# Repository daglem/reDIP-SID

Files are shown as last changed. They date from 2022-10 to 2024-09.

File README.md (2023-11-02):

# reDIP SID

## MOS 6581/8580 SID FPGA emulation platform
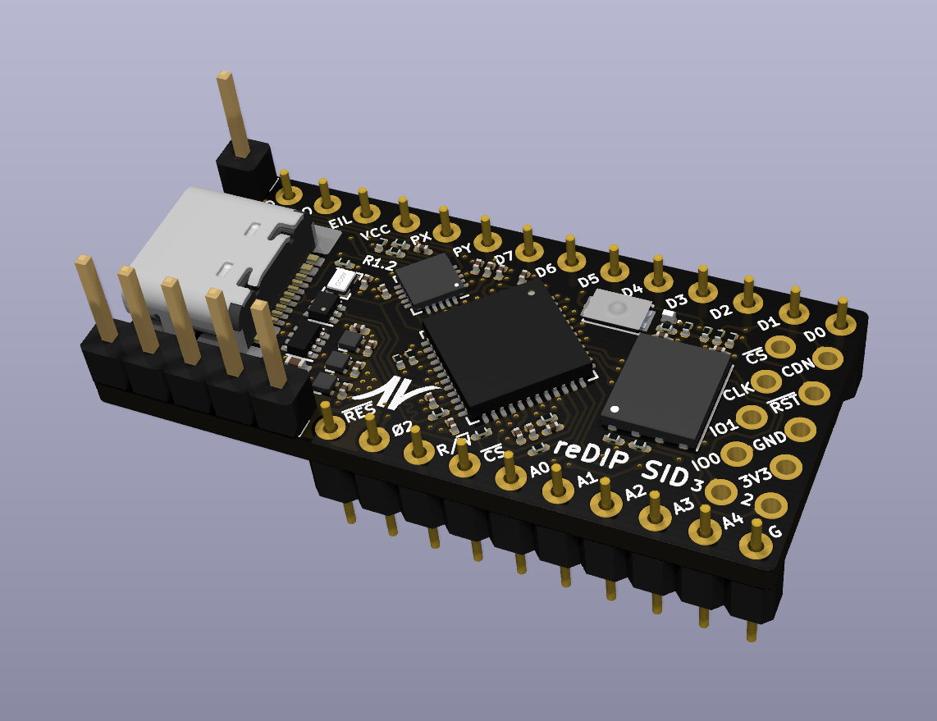
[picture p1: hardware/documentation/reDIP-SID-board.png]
Board


## Overview
The reDIP SID is an open source hardware development board which combines the following in a DIP-28 size package:

* Lattice iCE40UP5K FPGA
* NXP SGTL5000 Audio Codec
* 128Mbit FLASH
* 64Mbit PSRAM
* User LED
* Push button
* USB-C receptacle for power and FPGA Full Speed USB
* 5V tolerant I/O

The reDIP SID provides a fully functional open source hardware platform for MOS 6581/8580 SID emulation.

The reDIP SID also aims to be a good no-frills generic choice for FPGA projects which may find use for audio and/or 5V tolerant I/O -
it should be ideal for for e.g. retro computer and synthesizer projects.

Designs for the iCE40UP5K FPGA can be processed by [yosys](https://github.com/YosysHQ/yosys/) and [nextpnr](https://github.com/YosysHQ/nextpnr/).

The board is supported by the DFU [Nitro Bootloader](https://github.com/no2fpga/no2bootloader/), facilitating simple updates over USB using e.g. [dfu-util](http://dfu-util.sourceforge.net/).

## General use

### I/O interfaces

#### Header pins:

* 12V / 9V input (for SID audio output DC bias / C64 model detection)
* 5V input
* 19 FPGA GPIO
* 3 FPGA current drive / open-drain I/O
* 5 audio pins (stereo line input, stereo line output, SID audio output)
* GND

All FPGA header I/O is 5V tolerant, and can drive 5V TTL. JP1 can be shorted to make the 5V input pin bidirectional, e.g. to power 5V TTL devices from USB VBUS.

Note that the line inputs are not AC coupled - AC coupling must be externally added for audio applications.
Without external AC coupling, the line inputs can conceivably be used as generic ADCs.

The 12V / 9V input is connected to the SGTL5000 mic input via a 1/6 ratio voltage divider.

#### SPI / programming header:

A separate header footprint is provided for (Q)SPI peripherals / flash programming, with pinout borrowed from the [iCEBreaker Bitsy](https://github.com/icebreaker-fpga/icebreaker).

The header provides a 3.3V output, which may be used to power external devices. The 3.3V rail is supplied by a 700mA LDO.

#### USB-C functions:

* 5V power
* FPGA Full Speed USB

## MOS 6581/8580 SID compatibility

The board is fully pin compatible with the venerable MOS 6581/8580 SID sound chip.

The board features three additional address pins which may be connected to the Commodore 64, in order to make a second SID chip appear e.g. at address D420, D500, or DE00.

There is also an additional EXT IN audio input pin for a second SID chip, and separate stereo line output pins which may be connected directly to audio equipment.
Either the SID GND pin or GND on the programming header may be used as audio ground.

Cycle accurate emulation of the SID chip has been implemented in [gateware](gateware/).

## Thanks

Big thanks go to [Sylvain "tnt" Munaut](https://github.com/smunaut/), who has not only implemented support for the reDIP SID in his [Nitro Bootloader](https://github.com/no2fpga/no2bootloader/),
but has also identified shortcomings, suggested feature improvements, and provided invaluable help to ensure that the board actually works.

Thanks must also go to [Aidan Dodds](https://github.com/bit-hack) and [Paul Sajna](https://github.com/sajattack)
for putting the first prototype through its paces working on Dodds' [icesid](https://github.com/bit-hack/icesid), with guidance from Munaut.

## Board Front
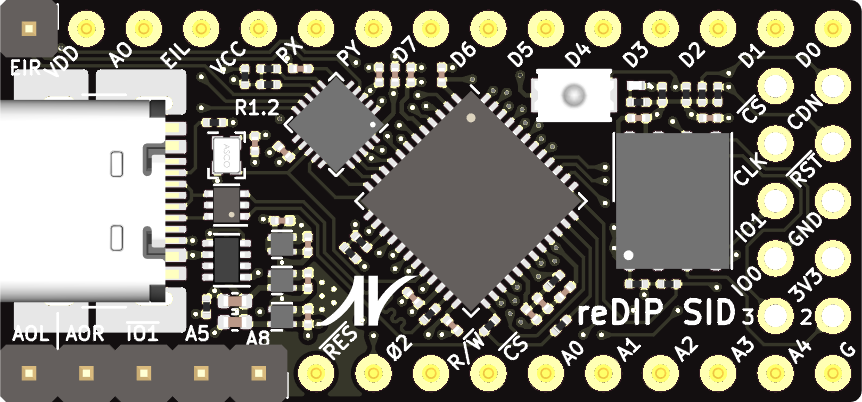
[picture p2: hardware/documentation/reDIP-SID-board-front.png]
Board Front


## Board Back
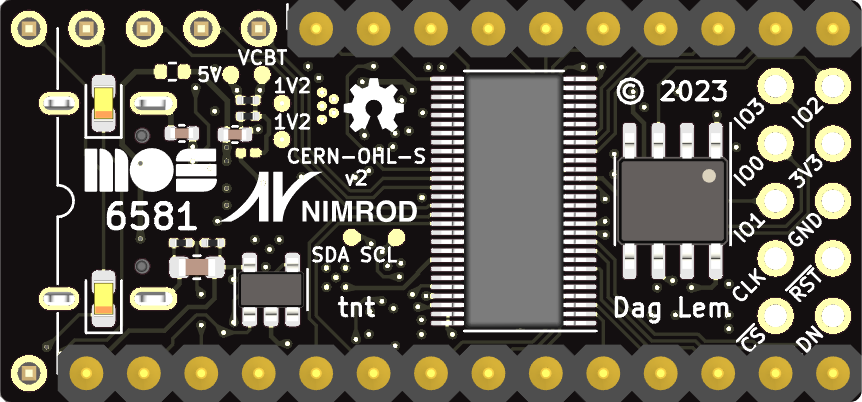
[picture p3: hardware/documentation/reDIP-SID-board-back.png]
Board Back


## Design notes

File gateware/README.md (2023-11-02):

# reDIP SID Gateware

## Description

The reDIP SID FPGA gateware provides high quality SID emulation for the
[reDIP SID](https://github.com/daglem/reDIP-SID) hardware.

The gateware owes its existence to [reSID](https://github.com/daglem/reSID),
the [SID internals documentation](https://github.com/libsidplayfp/SID_schematics/wiki)
by Leandro "drfiemost" Nini and Dieter "ttlworks" Mueller, auxiliary code and
guidance from Sylvain "tnt" Munaut, and a lot of work :-)

The gateware implements cycle accurate emulation of the SID digital logic, and
quite a few SID analog peculiarities. In order to make reasonably accurate
emulation of some of these fit in the iCE40UP5K FPGA, a few novelties have been
invented:

* Combined sawtooth/triangle and pulse/sawtooth/triangle waveforms without lookup tables.
* MOS6581 waveform, envelope, and filter cutoff DAC emulation without lookup tables.
* Parameterizable filter cutoff curves requiring only a single 16kbit lookup table.

Furthermore, FPGA resources are shared by [pipelining](Pipelining.md) and
time-division multiplexing. This is in contrast to the real SID chip, where
there was sufficient die area to simply repeat functional modules for each
voice.

By default, a single MOS6581 chip is emulated. The gateware also implements
MOS8580 emulation and simultaneous emulation of two chips, however runtime
configuration of these features are not yet implemented.

## Installation

The gateware may be installed on the reDIP SID hardware via USB using
[dfu-util](https://dfu-util.sourceforge.net/):

* Connect a USB cable to enter the bootloader. The green LED should start blinking.
* Install the gateware with `./flash.sh` (Linux / Mac OS) or `flash.bat` (Windows).
* Disconnect USB. If the board is still powered, then press the user button to boot.

Depending on the previously installed gateware, in order to enter the
bootloader it may be required to keep the user button pressed while powering up
the board.

## License

This gateware is part of reDIP SID, a MOS 6581/8580 SID FPGA emulation platform.
Copyright (C) 2022 - 2023  Dag Lem \<resid@nimrod.no\>

The source describes Open Hardware and is licensed under the CERN-OHL-S v2.

You may redistribute and modify the source and make products using it under
the terms of the [CERN-OHL-S v2](https://ohwr.org/cern_ohl_s_v2.txt).

This source is distributed WITHOUT ANY EXPRESS OR IMPLIED WARRANTY,
INCLUDING OF MERCHANTABILITY, SATISFACTORY QUALITY AND FITNESS FOR A
PARTICULAR PURPOSE. Please see the CERN-OHL-S v2 for applicable conditions.

Source location: [https://github.com/daglem/reDIP-SID](https://github.com/daglem/reDIP-SID)

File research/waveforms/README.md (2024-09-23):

# OSC3 samples of combined waveforms

MOS6581 waveform samples are supplied by Tuomas "Trurl" Rantala,
generated by combsample.prg for a chip marked 6581R4AR 3488.

MOS8580 waveforms samples are taken from reSID.

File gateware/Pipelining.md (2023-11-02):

# Pipelining

In order to make accurate SID emulation fit on a Lattice iCE40UP5K FPGA, it is
necessary to use pipelining and time-division multiplexing of resources.

Two synchronized pipelines are implemented; the voice pipeline and the filter
pipeline. The combined pipelines have a total of 14 pipeline stages. Two SID
chips are emulated, with audio outputs ready at cycle 15 and 20, respectively.

## Voice pipeline

The voice pipeline combines several SID modules, and produces one voice output
per cycle for two SID chips. The table below depicts the data path for SID 1,
voice 1.

| Stages | Module | Cycle 1 | Cycle 2 | Cycle 3 | Cycle 4 | Cycle 5 | Cycle 6 | Cycle 7 | Cycle 8 |
|  ----: | ---| --- |--- | --- | --- | --- | --- | --- | --- |
|  1 - 3 | Control registers  | Write voice 1  | Write voice 2  | Write voice 3  | | | | | |
|  2 - 4 | Oscillator | | Update osc. 1  | Update osc. 2  | Sync osc. 1-3  | | | | |
|  2 - 6 | Waveform generator | | Buffer pulse 1 | Buffer pulse 2 | Buffer pulse 3 | Waveform select / update | Waveform writeback | | |
|  6 | Envelope generator | | | | | | Update counters | | |
|  6 - 7 | Voice DCA | | | | | | Buffer wav/env | DCA = wav*env | |
| | | | | | | | | | Voice 1 out |

The voice pipeline starts on the falling edge of the ϕ₂ clock, brought into the
FPGA clock domain by a two-stage synchronizer.

As can be seen from the table above, output for voice 1 is ready on cycle
8. Outputs from the waveform and envelope generators are ready on cycle 6, so
data for the read-only registers OSC3 and ENV3 are also ready on cycle 8 (6 +
2).

The oscillator module adds a latency of two cycles; this is required for
synchronization of oscillators.

In order to meet MOS6510 bus timing, writes to the filter control registers for
SID 1 and 2 are included in the voice pipeline at cycle 1 and 4, respectively.
This is not shown in the table above.

## Filter pipeline

A separate pipeline is used to update filter state variables and produce audio
outputs for the two SID chips. The table below depicts the data path for the
audio output of SID 1.

| Stages | Description | Cycle 1 | Cycle 2  | Cycle 3  | Cycle 4 | Cycle 5 | Cycle 6 | Cycle 7 | Cycle 8 | Cycle 9 |
| -----: | --- | --- | ---| ---| --- | ---| --- | --- | --- | --- |
|  1 - 5 | Direct path mux / sum | vd = 0 | vd += v1 | vd += v2 | vd += v3 | vd += extin | (vd2 = 0, buffer vd1) | | | |
|  1 - 5 | Filter input mux / sum  | vi = 0 | vi += v1 | vi += v2 | vi += v3 | vi += extin | (vi2 = 0) | | | |
|  2 - 4 | Computation of factors  | | 1/Q, fc  | w0 | w0 | | | | | |
|  4 - 8 | Multiply-add | | | | 0 - w0*vbp | 0 - w0*vhp | -(vlp + vi) + 1/Q*vbp | | vol*(vd + vf) | |
|  5 - 7 | Filter state update | | | | | vlp = vlp + muladd | vbp = vbp + muladd | vhp = muladd | | |
|  4 - 7 | Filter path mux / sum | | | | vf = 0 | vf += vlp | vf += vbp | vf += vhp | | |
| | | | | | | | | | | Audio 1 out |

The filter pipeline starts at voice pipeline cycle 7. At filter pipeline cycles
4 and 5, idle cycles are injected in the voice pipeline (at cycle 10). As can
be seen from the table above, filter pipeline cycles 5 and 6 are used to mux
and sum in SID 1 EXT IN, and to initialize voice accumulators for SID 2.

## Timing for register read / write

Read / write of SID registers is done while the ϕ₂ clock is high.

In the following we will assume that we have a minimum of 20 FPGA cycles
available between each falling edge of ϕ₂. At a 24MHz FPGA clock, this
corresponds to a 1.2MHz clock, or a 1.02MHz NTSC C64 clock with a cycle to
cycle (C2C) jitter peak value of 147ns, or 15%.

On writes, the MOS6510 holds address and data signals for a minimum of 10ns
after the falling edge of ϕ₂ (THA and THR in the datasheet). The reDIP SID
gateware takes advantage of this by using iCEGate™ latches to freeze the
signals for as long as ϕ₂ is low. According to the MOS6510 datasheet, at a 1MHz
clock, the maximum pulse width of ϕ₂ is 510ns. Assuming that the corresponding
minimum period between the falling and rising edge of ϕ₂ is then in the
ballpark of 490ns, we have 20*490/1000 = 9.8 FPGA cycles available for
writes. Accounting for two cycles spent to bring ϕ₂ into the FPGA clock domain,
we are still within margin as the last SID register is written at cycle 6 in
the voice pipeline.

For reads, the MOS6510 datasheet specifies a minimum Data Stability Time Period
(TDSU) of 100ns, i.e. data must be output on the data bus at least 100ns before
the falling edge of ϕ₂. SID 1 OSC3/ENV3 are ready on cycle 8 in the voice
pipeline, i.e. SID 2 OSC3/ENV3 are ready on cycle 8 + 3 = 11, just after the
voice pipeline is paused for two cycles. Accounting for another two cycles
spent to bring ϕ₂ into the FPGA clock domain, a cycle to register OSC3/ENV3,
and a cycle for registered pin outputs, we get a minimum TDSU of (20 - 11 - 2 -
2 - 1 - 1)/24Mhz = 125ns, which is within specification.

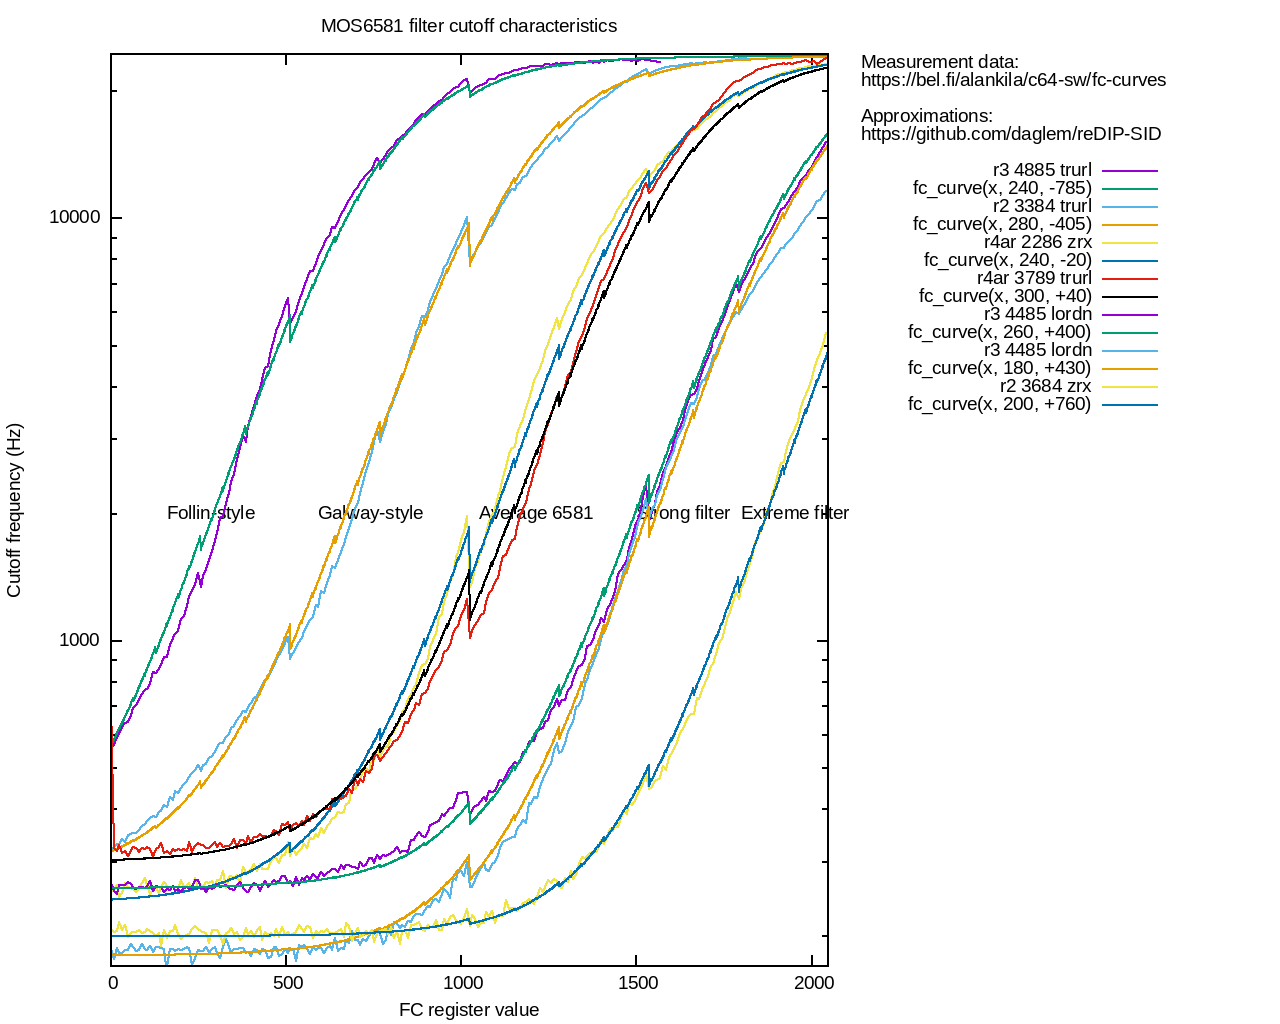
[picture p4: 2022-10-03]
research/fc-curves.png

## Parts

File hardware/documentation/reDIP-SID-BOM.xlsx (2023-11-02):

Prj: | reDIP SID |  |  |  |  |  |  | Board Qty: | 100
Co.: | Nimrod |  |  |  |  |  |  | Unit Cost: | $21.82
Prj date: | Thu 02 Nov 2023 08:37:31 PM CET |  |  |  |  |  |  | Total Cost: | $2181.75 |  |  |  |  | $2104.09 | 29 of 35 parts found |  |  |  |  | $2189.40 | 31 of 35 parts found
$ date: | 2023-11-02 20:37:40
Global Part Info |  |  |  |  |  |  |  |  |  | Digi-Key |  |  |  |  |  | Mouser
Refs | Value | Desc | Notes | Footprint | Manf | Manf# | Qty | Unit$ | Ext$ | Avail | Purch | Unit$ | MOQ | Ext$ | Cat# | Avail | Purch | Unit$ | MOQ | Ext$ | Cat#
C1-C3,C5 | 1uF | CAP CER 2.2uF 16V 10% X6S 0402 | 5V DC DERATED TO 1uF | C_0402_1005Metric | Murata | GRM155C81C225KE11D (https://www.murata.com/products/productdetail.aspx?partno=GRM155C81C225KE11D) | 400 | $0.088 | $35.32 | 66508 |  | $0.088 | 1 | $35.32 | 490-14595-1-ND (https://www.digikey.com/en/products/detail/murata-electronics/GRM155C81C225KE11D/4905093) | 57211 |  | $0.089 | 1 | $35.60 | 81-GRM155C81C225KE1D (https://no.mouser.com/ProductDetail/Murata-Electronics/GRM155C81C225KE11D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)
C4,C8,C23 | 1uF | CAP CER 1uF 6.3V 20% X6S 0201 | 1.2V DC | C_0201_0603Metric | Murata | GRM033C80J105ME05D (https://www.murata.com/products/productdetail.aspx?partno=GRM033C80J105ME05D) | 300 | $0.054 | $16.20 | 1440111 |  | $0.078 | 1 | $23.34 | 490-13218-1-ND (https://www.digikey.com/en/products/detail/murata-electronics/GRM033C80J105ME05D/5877381) | 777764 |  | $0.054 | 1 | $16.20 | 81-GRM033C80J105ME5D (https://no.mouser.com/ProductDetail/Murata-Electronics/GRM033C80J105ME05D?qs=P8zzrVhehaso8Xg5mhsu3Q%3D%3D)
C6,C7,C16 | 1uF | CAP CER 2.2uF 10V 20% X5R 0201 | 3.3V DC DERATED TO 1uF | C_0201_0603Metric | Murata | GRM035R61A225ME01D (https://www.murata.com/products/productdetail.aspx?partno=GRM035R61A225ME01D) | 300 |  |  |  |  |  |  |  |  | NonStk |  |  | 10000 |  | 81-GRM035R61A225ME1D (https://no.mouser.com/ProductDetail/Murata-Electronics/GRM035R61A225ME01D?qs=pUKx8fyJudAGsIsikE8KgA%3D%3D)
C9-C12,C17-C22,C24,C25 | 0.1uF | CAP CER 0.22uF 6.3V 20% X5R 0201 | C9,C20: 1.2V DC DERATED TO 0.1uF C12: 1.65V DC VAG DERATED TO 0.1uF C10,C11,C17-C19,C21,C22,C24,C25: 3.3V DC DERATED TO 0.1uF | C_0201_0603Metric | Murata | GRM033R60J224ME90D (https://www.murata.com/products/productdetail.aspx?partno=GRM033R60J224ME90D) | 1200 | $0.005 | $5.70 | 14729 |  | $0.005 | 1 | $5.70 | 490-11973-1-ND (https://www.digikey.com/en/products/detail/murata-electronics/GRM033R60J224ME90D/4904674) | 84464 |  | $0.005 | 1 | $6.00 | 81-GRM033R60J224ME9D (https://no.mouser.com/ProductDetail/Murata-Electronics/GRM033R60J224ME90D?qs=2W5sgKM%2F3704nCcQ8ai7mA%3D%3D)
C13 | 1uF | CAP CER 4.7uF 16V 20% X5R 0603 | 9V/12V DC DERATED TO 1uF | C_0603_1608Metric | Murata | GRM188R61C475ME11D (https://www.murata.com/products/productdetail.aspx?partno=GRM188R61C475ME11D) | 100 | $0.055 | $5.50 | 7936 |  | $0.078 | 1 | $7.80 | 490-14638-1-ND (https://www.digikey.com/en/products/detail/murata-electronics/GRM188R61C475ME11D/4905343) | 4417 |  | $0.055 | 1 | $5.50 | 81-GRM188R61C475ME1D (https://no.mouser.com/ProductDetail/Murata-Electronics/GRM188R61C475ME11D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)
C14,C15 | 10uF | CAP TANT 10uF 6.3V 20% 0603 | 1.65V DC 1.5V AC AUDIO | CP_EIA-1608-08_AVX-J | Vishay | TMCJ0J106MTRF (https://www.vishay.com/docs/40176/tmcj.pdf) | 200 | $0.153 | $30.68 | 6427 |  | $0.153 | 1 | $30.68 | 718-2355-1-ND (https://www.digikey.com/en/products/detail/vishay-sprague/TMCJ0J106MTRF/10107287) | 3922 |  | $0.155 | 1 | $31.00 | 74-TMCJ0J106MTRF (https://no.mouser.com/ProductDetail/Vishay-Sprague/TMCJ0J106MTRF?qs=WatphXlIDnwX%2FmRnq8idiA%3D%3D)
D1 | SML-LX0201UPGC-TR | LED GREEN Vf=2.5V If=2mA 100mcd 0201 |  | SML-LX0201 | Lumex | SML-LX0201UPGC-TR (https://www.lumex.com/datasheet/SML-LX0201UPGC-TR.html) | 100 | $0.105 | $10.50 | 29150 |  | $0.116 | 1 | $11.58 | 67-2282-1-ND (https://www.digikey.com/en/products/detail/lumex-opto-components-inc/SML-LX0201UPGC-TR/7430416) | 10775 |  | $0.105 | 1 | $10.50 | 696-SMLLX0201UPGCTR (https://no.mouser.com/ProductDetail/Lumex/SML-LX0201UPGC-TR?qs=EU6FO9ffTwehGqVaOLwCAA%3D%3D)
J1 | Conn_01x01 | CONN HDR SQ PIN 0.64mm 1 POS .100" GOLD MATING 6mm TAIL 3mm |  | PinHeader_1x01_P2.54mm_Vertical | XKB | X6511WV-01H-C60D30 (https://www.helloxkb.com/Home/Goods/goodsInfo/id/99582.html) | 100
J2 | Conn_01x05 | CONN HDR SQ PIN 0.64mm 5 POS .100" GOLD MATING 6mm TAIL 3mm |  | PinHeader_1x05_P2.54mm_Vertical | XKB | X6511WV-05H-C60D30 (https://www.helloxkb.com/Home/Goods/goodsInfo/id/99586.html) | 100
J3 | Conn_01x14 | CONN HDR CIRCULAR PIN 0.5mm 14 POS .100" GOLD MATING 3.5mm TAIL 3mm |  | PinHeader_1x14_P2.54mm_Vertical_Machined | XKB | X5511WV-14-C35D35-1000 (https://www.helloxkb.com/Home/Goods/goodsInfo/id/72364.html) | 100
J4 | Conn_01x10 | CONN HDR CIRCULAR PIN 0.5mm 10 POS .100" GOLD MATING 3.5mm TAIL 3mm |  | PinHeader_1x10_P2.54mm_Vertical_Machined | XKB | X5511WV-10-C35D35-1000 (https://www.helloxkb.com/Home/Goods/goodsInfo/id/72360.html) | 100
J5 | USB4105-GF-A | CONN USB-C | REPLACEMENT PARTS: HRO TYPE-C-31-M-12 | USB_C_Receptacle_HRO_TYPE-C-31-M-12 | GCT | USB4105-GF-A (https://gct.co/files/drawings/usb4105.pdf?v=7f82f35c-3647-4bcd-a100-0fb9f1f8c8e2) | 100 | $0.560 | $56.00 | 1990 |  | $0.618 | 1 | $61.77 | 2073-USB4105-GF-ACT-ND (https://www.digikey.com/en/products/detail/gct/USB4105-GF-A/11198441) | 179515 |  | $0.560 | 1 | $56.00 | 640-USB4105-GF-A (https://no.mouser.com/ProductDetail/GCT/USB4105-GF-A?qs=KUoIvG%2F9IlY%2FMLlBMpStpA%3D%3D)
R1 | 1k | RES 1kΩ 50mW 1% 0201 |  | R_0201_0603Metric | Panasonic | ERJ1GNF1001C (https://industrial.panasonic.com/ww/products/pt/general-purpose-chip-resistors/models/ERJ1GNF1001C) | 100 | $0.025 | $2.47 | 3119937 |  | $0.025 | 1 | $2.47 | P122413CT-ND (https://www.digikey.com/en/products/detail/panasonic-electronic-components/ERJ-1GNF1001C/2036112) | 1623010 |  | $0.026 | 1 | $2.60 | 667-ERJ-1GNF1001C (https://no.mouser.com/ProductDetail/Panasonic/ERJ-1GNF1001C?qs=nuXzIS8loXFEaL2ux1uJzQ%3D%3D)
R3 | 6.2k | RES 6.2kΩ 50mW 1% 0201 |  | R_0201_0603Metric | Panasonic | ERJ1GNF6201C (https://industrial.panasonic.com/ww/products/pt/general-purpose-chip-resistors/models/ERJ1GNF6201C) | 100 | $0.025 | $2.47 | 60694 |  | $0.025 | 1 | $2.47 | P123105CT-ND (https://www.digikey.com/en/products/detail/panasonic-electronic-components/ERJ-1GNF6201C/2036203) | 26038 |  | $0.026 | 1 | $2.60 | 667-ERJ-1GNF6201C (https://no.mouser.com/ProductDetail/Panasonic/ERJ-1GNF6201C?qs=nuXzIS8loXFvoqcBbLwN7g%3D%3D)
R4,R5,R15,R19 | 2.2k | RES 2.2kΩ 50mW 5% 0201 |  | R_0201_0603Metric | Panasonic | ERJ1GNJ222C (https://industrial.panasonic.com/ww/products/pt/general-purpose-chip-resistors/models/ERJ1GNJ222C) | 400 | $0.013 | $5.32 | 249575 |  | $0.013 | 1 | $5.32 | P123277CT-ND (https://www.digikey.com/en/products/detail/panasonic-electronic-components/ERJ-1GNJ222C/2035795) | 93933 |  | $0.014 | 1 | $5.60 | 667-ERJ-1GNJ222C (https://no.mouser.com/ProductDetail/Panasonic/ERJ-1GNJ222C?qs=wTZ%2FFzl837bSaI4SM06fJg%3D%3D)
R6 | 1.5k | RES 1.5kΩ 50mW 5% 0201 |  | R_0201_0603Metric | Panasonic | ERJ1GNJ152C (https://industrial.panasonic.com/ww/products/pt/general-purpose-chip-resistors/models/ERJ1GNJ152C) | 100 | $0.013 | $1.33 | 104676 |  | $0.013 | 1 | $1.33 | P123246CT-ND (https://www.digikey.com/en/products/detail/panasonic-electronic-components/ERJ-1GNJ152C/2035791) | 135542 |  | $0.014 | 1 | $1.40 | 667-ERJ-1GNJ152C (https://no.mouser.com/ProductDetail/Panasonic/ERJ-1GNJ152C?qs=nuXzIS8loXEN14at7OEUHw%3D%3D)
R7 | 100k | RES 100kΩ 50mW 1% 0201 |  | R_0201_0603Metric | Panasonic | ERJ1GNF1003C (https://industrial.panasonic.com/ww/products/pt/general-purpose-chip-resistors/models/ERJ1GNF1003C) | 100 | $0.019 | $1.90 | 2937878 |  | $0.019 | 1 | $1.90 | P122655CT-ND (https://www.digikey.com/en/products/detail/panasonic-electronic-components/ERJ-1GNF1003C/2036340) | 448736 |  | $0.026 | 1 | $2.60 | 667-ERJ-1GNF1003C (https://no.mouser.com/ProductDetail/Panasonic/ERJ-1GNF1003C?qs=nuXzIS8loXFCVaxpzTie8Q%3D%3D)
R8-R10 | 20k | RES 20kΩ 50mW 1% 0201 |  | R_0201_0603Metric | Panasonic | ERJ1GNF2002C (https://industrial.panasonic.com/ww/products/pt/general-purpose-chip-resistors/models/ERJ1GNF2002C) | 300 | $0.014 | $4.20 | 378396 |  | $0.019 | 1 | $5.70 | P122813CT-ND (https://www.digikey.com/en/products/detail/panasonic-electronic-components/ERJ-1GNF2002C/2036258) | 964117 |  | $0.014 | 1 | $4.20 | 667-ERJ-1GNF2002C (https://no.mouser.com/ProductDetail/Panasonic/ERJ-1GNF2002C?qs=nuXzIS8loXGlEdsCEHpvVg%3D%3D)
R11,R16-R18,R22 | 10k | RES 10kΩ 50mW 1% 0201 |  | R_0201_0603Metric | Panasonic | ERJ1GNF1002C (https://industrial.panasonic.com/ww/products/pt/general-purpose-chip-resistors/models/ERJ1GNF1002C) | 500 | $0.013 | $6.63 | 2247581 |  | $0.013 | 1 | $6.63 | P122414CT-ND (https://www.digikey.com/en/products/detail/panasonic-electronic-components/ERJ-1GNF1002C/2036226) | 2408384 |  | $0.014 | 1 | $7.00 | 667-ERJ-1GNF1002C (https://no.mouser.com/ProductDetail/Panasonic/ERJ-1GNF1002C?qs=nuXzIS8loXE96jG2vMMQNw%3D%3D)
R12,R13 | 5.1k | RES 5.1kΩ 50mW 5% 0201 |  | R_0201_0603Metric | Panasonic | ERJ1GNJ512C (https://industrial.panasonic.com/ww/products/pt/general-purpose-chip-resistors/models/ERJ1GNJ512C) | 200 | $0.007 | $1.40 | 135347 |  | $0.013 | 1 | $2.50 | P123340CT-ND (https://www.digikey.com/en/products/detail/panasonic-electronic-components/ERJ-1GNJ512C/2035804) | 27271 |  | $0.007 | 1 | $1.40 | 667-ERJ-1GNJ512C (https://no.mouser.com/ProductDetail/Panasonic/ERJ-1GNJ512C?qs=wTZ%2FFzl837alr2HcCwgorQ%3D%3D)
R14 | 100 | RES 100Ω 50mW 5% 0201 |  | R_0201_0603Metric | Panasonic | ERJ1GNJ101C (https://industrial.panasonic.com/ww/products/pt/general-purpose-chip-resistors/models/ERJ1GNJ101C) | 100 | $0.007 | $0.70 | 231675 |  | $0.013 | 1 | $1.25 | P123220CT-ND (https://www.digikey.com/en/products/detail/panasonic-electronic-components/ERJ-1GNJ101C/2035763) | 91154 |  | $0.007 | 1 | $0.70 | 667-ERJ-1GNJ101C (https://no.mouser.com/ProductDetail/Panasonic/ERJ-1GNJ101C?qs=nuXzIS8loXGN5So4aOOV1Q%3D%3D)
R20,R21 | 0 | RES 0Ω 50mW 1% 0201 |  | R_0201_0603Metric | Panasonic | ERJ1GN0R00C (https://industrial.panasonic.com/ww/products/pt/general-purpose-chip-resistors/models/ERJ1GN0R00C) | 200 | $0.007 | $1.40 | 4106767 |  | $0.012 | 1 | $2.38 | P15979CT-ND (https://www.digikey.com/en/products/detail/panasonic-electronic-components/ERJ-1GN0R00C/3982613) | 2852273 |  | $0.007 | 1 | $1.40 | 667-ERJ-1GN0R00C (https://no.mouser.com/ProductDetail/Panasonic/ERJ-1GN0R00C?qs=7CTG1529Hzj3BLXuZjatmA%3D%3D)
R23 | 22 | RES 22Ω 50mW 1% 0201 |  | R_0201_0603Metric | Panasonic | ERJ1GNF22R0C (https://industrial.panasonic.com/ww/products/pt/general-purpose-chip-resistors/models/ERJ1GNF22R0C) | 100 | $0.014 | $1.40 | 485335 |  | $0.019 | 1 | $1.90 | P122843CT-ND (https://www.digikey.com/en/products/detail/panasonic-electronic-components/ERJ-1GNF22R0C/2035920) | 180139 |  | $0.014 | 1 | $1.40 | 667-ERJ-1GNF22R0C (https://no.mouser.com/ProductDetail/Panasonic/ERJ-1GNF22R0C?qs=nuXzIS8loXH5CLca8fBHhg%3D%3D)
SW1 | KXT311LHS | SW TACT 100gf 3.0x2.0 mm |  | SW_SPST_CK_KXT3 | C&K | KXT311LHS (https://www.ckswitches.com/media/1465/kxt3.pdf) | 100 | $0.240 | $23.98 | 34386 |  | $0.240 | 1 | $23.98 | CKN10777CT-ND (https://www.digikey.com/en/products/detail/c-k/KXT-311-LHS/6599752) | 10460 |  | $0.240 | 1 | $24.00 | 611-KXT311LHS (https://no.mouser.com/ProductDetail/CK/KXT311LHS?qs=%2FQ2qp2Z%2FWFxZqSWVDr5IpA%3D%3D)
U1,U3 | NCP115AMX120TCG | IC REG LDO 1.2V 300mA XDFN4 |  | CASE_711AJ_1.0x1.0mm_P0.65mm | onsemi | NCP115AMX120TCG (https://www.onsemi.com/pdf/datasheet/ncp115-d.pdf) | 200 | $0.118 | $23.60 | 7412 |  | $0.143 | 1 | $28.66 | NCP115AMX120TCGOSCT-ND (https://www.digikey.com/en/products/detail/onsemi/NCP115AMX120TCG/9829201) | 11436 |  | $0.118 | 1 | $23.60 | 863-NCP115AMX120TCG (https://no.mouser.com/ProductDetail/onsemi/NCP115AMX120TCG?qs=l7cgNqFNU1iSEavmMXBgHw%3D%3D)
U2 | NCP167AMX330TBG | IC REG LDO 3.3V 700mA XDFN4 |  | CASE_711AJ_1.0x1.0mm_P0.65mm | onsemi | NCP167AMX330TBG (https://www.onsemi.com/pdf/datasheet/ncp167-d.pdf) | 100 | $0.291 | $29.10 | 12673 |  | $0.347 | 1 | $34.69 | NCP167AMX330TBGOSCT-ND (https://www.digikey.com/en/products/detail/onsemi/NCP167AMX330TBG/9169759) | 66705 |  | $0.291 | 1 | $29.10 | 863-NCP167AMX330TBG (https://no.mouser.com/ProductDetail/onsemi/NCP167AMX330TBG?qs=MLItCLRbWswBL%252BIllRiU9w%3D%3D)
U4 | LM66200DRLR | IC DUAL IDEAL DIODE |  | SOT-5X3 | TI | LM66200DRLR (https://www.ti.com/lit/ds/symlink/lm66200.pdf) | 100 | $0.458 | $45.80 | 15041 |  | $0.460 | 1 | $46.00 | 296-LM66200DRLRCT-ND (https://www.digikey.com/en/products/detail/texas-instruments/LM66200DRLR/15856663) | 1147 |  | $0.458 | 1 | $45.80 | 595-LM66200DRLR (https://no.mouser.com/ProductDetail/Texas-Instruments/LM66200DRLR?qs=Rp5uXu7WBW90hnpZAkIOdQ%3D%3D)
U5 | SN74CBT16211CDGVR | IC BUS SWITCH TVSOP-56 | REPLACEMENT PART: SN74CBT16211ADGVR | Texas_TVSOP-56_4.4x11.3mm_P0.4mm | TI | SN74CBT16211ADGVR (https://www.ti.com/lit/ds/symlink/sn74cbt16211c.pdf) | 100 | $1.350 | $135.00 | 2945 |  | $1.350 | 1 | $135.02 | 296-6389-1-ND (https://www.digikey.com/en/products/detail/texas-instruments/SN74CBT16211ADGVR/377843) | 1594 |  | $1.350 | 1 | $135.00 | 595-SNCBT16211ADGVR (https://no.mouser.com/ProductDetail/Texas-Instruments/SN74CBT16211ADGVR?qs=6gY4t2uohMy2xZG8X83aAA%3D%3D)
U6 | SGTL5000XNLA3 | IC AUDIO CODEC UQFN-20 | ALTERNATIVE PART #: SGTL5000XNLA3R2 | QFN-20-1EP_3x3mm_P0.4mm_EP1.65x1.65mm | NXP | SGTL5000XNLA3 (https://www.nxp.com/docs/en/data-sheet/SGTL5000.pdf) | 100 | $4.120 | $412.00 | 21164 |  | $4.120 | 1 | $412.04 | SGTL5000XNLA3-ND (https://www.digikey.com/en/products/detail/nxp-usa-inc/SGTL5000XNLA3/2186899) | 45668 |  | $4.120 | 1 | $412.00 | 841-SGTL5000XNLA3 (https://no.mouser.com/ProductDetail/NXP-Semiconductors/SGTL5000XNLA3?qs=g5o6z0NmdpSQCyEqtPbKVg%3D%3D)
U7 | NUF2042XV6 | IC USB TERMINATOR ESD PROTECTION SOT-563 |  | SOT-563 | onsemi | NUF2042XV6T1G (https://www.onsemi.com/pdf/datasheet/nuf2030xv6-d.pdf) | 100 | $0.305 | $30.50 | 137050 |  | $0.366 | 1 | $36.58 | NUF2042XV6T1GOSCT-ND (https://www.digikey.com/en/products/detail/onsemi/NUF2042XV6T1G/1484972) | 41106 |  | $0.305 | 1 | $30.50 | 863-NUF2042XV6T1G (https://no.mouser.com/ProductDetail/onsemi/NUF2042XV6T1G?qs=ZXBb0xZ9WeAV3XcAwewBSw%3D%3D)
U8 | MCP6H01T-E/OT | IC OPAMP SOT-23-5 |  | SOT-23-5 | Microchip | MCP6H01T-E/OT (https://www.microchip.com/en-us/product/MCP6H01) | 100 | $0.617 | $61.70 | 97769 |  | $0.620 | 1 | $62.00 | MCP6H01T-E/OTCT-ND (https://www.digikey.com/en/products/detail/microchip-technology/MCP6H01T-E-OT/3046664) | 114627 |  | $0.617 | 1 | $61.70 | 579-MCP6H01T-E/OT (https://no.mouser.com/ProductDetail/Microchip-Technology/MCP6H01T-E-OT?qs=fgHA1UgJI8BCRjn9O%2FfGrw%3D%3D)
U9 | APS6404L-3SQR | IC PSRAM 64Mbit SOP-8 | REPLACEMENT PART: Lyontek LY68L6400SLIT | SOP-8_3.9x4.9mm_P1.27mm | AP | APS6404L-3SQR-SN (https://www.apmemory.com/wp-content/uploads/APM_PSRAM_E3_QSPI-APS6404L-3SQR-v2.4-KGD_PKG.pdf) | 100 | $1.160 | $116.00 |  |  |  |  |  |  | 19998 |  | $1.160 | 1 | $116.00 | 878-APS6404L-3SQR-SN (https://no.mouser.com/ProductDetail/AP-Memory/APS6404L-3SQR-SN?qs=IS%252B4QmGtzzqsn3S5xo%2FEEg%3D%3D)
U10 | W25Q128JVPIM | IC FLASH 128Mbit WSON-8 | ALTERNATIVE PART #: W25Q128JVPIM TR | WSON-8-1EP_6x5mm_P1.27mm_EP3.4x4.3mm | Winbond | W25Q128JVPIM (https://www.winbond.com/resource-files/W25Q128JV%20RevI%2008232021%20Plus.pdf) | 100 | $1.390 | $139.00 | 3456 |  | $1.391 | 1 | $139.13 | W25Q128JVPIM-ND (https://www.digikey.com/en/products/detail/winbond-electronics/W25Q128JVPIM/6819719) | 5182 |  | $1.390 | 1 | $139.00 | 454-W25Q128JVPIM (https://no.mouser.com/ProductDetail/Winbond/W25Q128JVPIM?qs=qSfuJ%252Bfl%2Fd62hi5N%252Bd7%252B%252BA%3D%3D)
U11 | ICE40UP5K-SG48I | IC FPGA QFN-48 |  | QFN-48-1EP_7x7mm_P0.5mm_EP5.6x5.6mm | Lattice | ICE40UP5K-SG48I (http://www.latticesemi.com/Products/FPGAandCPLD/iCE40UltraPlus) | 100 | $8.450 | $845.00 | NonStk |  | $8.450 | 1 | $845.00 | 220-2212-1-ND (https://www.digikey.com/en/products/detail/lattice-semiconductor-corporation/ICE40UP5K-SG48I/7785190) | 12647 |  | $8.500 | 1 | $850.00 | 842-ICE40UP5K-SG48I (https://no.mouser.com/ProductDetail/Lattice/ICE40UP5K-SG48I?qs=Rp3RbKSfAt3UqOG1AN4%2FAg%3D%3D)
X1 | ASCO-24.000MHZ-EK-T3 | OSC 24 MHz 30 ppm 1.6x1.2 mm | REPLACEMENT PARTS: ECS ECS-1612MV-240-CN-TR | Oscillator_SMD-4Pin_1.6x1.2mm | Abracon | ASCO-24.000MHZ-EK-T3 (https://abracon.com/Oscillators/ASCO.pdf) | 100 | $1.310 | $130.95 | 11368 |  | $1.310 | 1 | $130.95 | 535-12073-1-ND (https://www.digikey.com/en/products/detail/abracon-llc/ASCO-24-000MHZ-EK-T3/4092550) | 4318 |  | $1.310 | 1 | $131.00 | 815-ASCO-24-EK-T3 (https://no.mouser.com/ProductDetail/ABRACON/ASCO-24.000MHZ-EK-T3?qs=DffVzuaNd2xIZg%252BriyLDUQ%3D%3D)
 |  |  |  |  |  |  |  | Total Purchase: | $0.00 | Buy here (https://www.digikey.com/ordering/shoppingcart) |  |  |  | $0.00 |  | Buy here (https://mouser.com/bom/) |  |  |  | $0.00
KiCost® v1.1.18 |  |  |  |  |  |  |  | Purchase description:

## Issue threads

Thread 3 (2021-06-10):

3v3 reg enable pin

bit-hack, 2021-06-10:
Hi there,

I was checking over the schematic and the design.  I have one small concern about the design surrounding the 1.2v regulator and the 3.3v regulator.  You have the 1.2v output driving the 3.3v enable pin.  Checking the datasheet for the 3.3v regulator however shows:

> Chip enable: Applying VEN < 0.4 V disables the regulator, Pulling VEN > 1.2 V enables the LDO

My concern is that the 1.2v output driving this pin is right on the threshold and if the 1.2v dips it could cause the 3.3v to turn off.  I seem to recall the ICE40 datasheet showing that the powerup sequence should have 1.2v starting before 3.3v which is why I guess its wired like this.

Would a simple RC circuit be better in this case driving the enable from the 5v rail?

bit-hack, 2021-06-10:
For reference this is the datasheet I was looking at: https://www.mouser.co.uk/datasheet/2/308/1/NCP167_D-2316956.pdf

daglem, 2021-06-10:
Great that you're looking into the design in such detail!

Yes, the bringup of the LDOs attempts to follow the power-up supply sequence recommended in the iCE40 UltraPlus datasheet.

I did actually read the NCP167 datasheet quite carefully, and I landed on that the design would be quite safe.
The wording in the datasheet indicates that there must be some leeway regarding the 1.2V figure: "If the EN pin voltage >1.2 V the device is *guaranteed* to be enabled." If you look at Figure 14 (Enable Voltage Threshold vs. Temperature), it would indeed seem that the 1.2V figure is extremely conservative.

Closed 2021-06-10.

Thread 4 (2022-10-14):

Can't find the ICE chip in the market

hexad, 2022-10-14:
There are literally 0 IC of this in the market, in order to build this.
Is this possible that the whole thing works with another FPGA chip that you can find in the market?

Perhaps one from the same product line?

daglem, 2022-10-18:
The availability of the iCE40UP5K FPGA is actually quite good, compared to other FPGAs in the market.
E.g. 25 000 are expected at Mouser in December.
I am not going to redesign the board for any other FPGA, as long as there are no superior options.

hexad, 2022-10-23:
Thanks for the Mouser tip! And for the excellent project!

Closed 2022-10-18.

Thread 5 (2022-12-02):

gerber?

sorgelig, 2022-12-02:
Hi!

Can you add gerber for those who have no KiCad installed?
I've tried to import it to Altium Designer (which i'm familiar to), but result wasn't good.

sorgelig, 2022-12-02:
figured it out

Closed 2022-12-02.

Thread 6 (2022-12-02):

about SN74CBT16211A

sorgelig, 2022-12-02:
Hi!

On schematics and BOM you've used CBT version with 5V TTL output, so you use voltage divider to get 4.3V which is probably still not good for FPGA. Why you are insisting on this particular version instead of CBTD or CB3T versions providing correct 3.3V level shifting?

daglem, 2022-12-04:
The CBT bus switch has a voltage drop of approximately 1V, hence a VCC of approximately 4.3V should yield the required 3.3V I/O.

The schematic documents how the voltage divider can be configured for CBT, CBTD, or CB3T bus switches.

sorgelig, 2022-12-05:
I understand the difference between all 3 versions. Just wonder if there is a specific reason to use exactly CBT version. Or you just used what you had in inventory?

Another question: about 128mbit FLASH. I guess it's possible to use 64Mbit version, right? I have flash programmer which supports W25Q64 but not W25Q128 and i don't have Diamond Programmer.

daglem, 2022-12-05:
The reason why the board is designed to support different bus switches is to increase the probability of getting hold of all the required components during chip shortages. The CBT switch had the highest stock and the lowest price at the time, and thus the BOM contains that. As mentioned, the board should work just fine with any of the bus switches, provided that the voltage divider is configured correctly. The previous version of the design contained the CBTD bus switch, and at least one person has tested the current design with the CBT bus switch.

I don't see any reason why the 64Mbit flash wouldn't work.

Closed 2022-12-04.

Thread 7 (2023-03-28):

dfu-util doesn't update

sorgelig, 2023-03-28:
Hello!
I'm trying to use dfu-util:

```
dfu-util.exe -d 1d50:6159,:6156 -a 0 -D redip_sid.bin -R
dfu-util 0.11

Copyright 2005-2009 Weston Schmidt, Harald Welte and OpenMoko Inc.
Copyright 2010-2021 Tormod Volden and Stefan Schmidt
This program is Free Software and has ABSOLUTELY NO WARRANTY
Please report bugs to http://sourceforge.net/p/dfu-util/tickets/

Warning: Invalid DFU suffix signature
A valid DFU suffix will be required in a future dfu-util release
Opening DFU capable USB device...
Device ID 1d50:6159
Device DFU version 0101
Claiming USB DFU (Run-Time) Interface...
Setting Alternate Interface zero...
Determining device status...
Device does not implement get_status, assuming appIDLE
Device really in Run-Time Mode, send DFU detach request...
Device will detach and reattach...
Lost device after RESET?
```

reDIP-SID disappears from device manager and left in state with CDONE LED ON.

daglem, 2023-03-30:
It should look like this (on Linux):
```
dfu-util -d 1d50:6159,:6156 -a 0 -D redip_sid.bin -R
dfu-util 0.11

Copyright 2005-2009 Weston Schmidt, Harald Welte and OpenMoko Inc.
Copyright 2010-2021 Tormod Volden and Stefan Schmidt
This program is Free Software and has ABSOLUTELY NO WARRANTY
Please report bugs to http://sourceforge.net/p/dfu-util/tickets/

dfu-util: Warning: Invalid DFU suffix signature
dfu-util: A valid DFU suffix will be required in a future dfu-util release
Opening DFU capable USB device...
Device ID 1d50:6156
Device DFU version 0101
Claiming USB DFU Interface...
Setting Alternate Interface #0 ...
Determining device status...
DFU state(2) = dfuIDLE, status(0) = No error condition is present
DFU mode device DFU version 0101
Device returned transfer size 4096
Copying data from PC to DFU device
Download	[=========================] 100%       104090 bytes
Download done.
DFU state(2) = dfuIDLE, status(0) = No error condition is present
Done!
Resetting USB to switch back to Run-Time mode
```
It seems like you don't get the device status from the bootloader, for some reason. I guess this could be caused either by dfu-util on your OS or the OS itself (I can't help with Windows), or by an incorrect bootloader. The bootloader should be built like this:
```
cd no2bootloader/gateware/ice40-stub/
make BOARD=redip-sid PRE_CLEAN=1 bootloader-clean
make BOARD=redip-sid bootloader
```
If you're using an FTDI cable / board, you would use iceprog for programming flash:
```
sudo iceprog build-tmp/bootloader.bin
```

sorgelig, 2023-03-31:
i use muacm.v netlist file from redip-sid repo. I guess it's pre-compilled netlist by you. Is it correct?
Currently i use my ROM Programmer G540 over that 10-pin connector. It's very very slow, but works. I hope i can make dfu working.
What driver version you use?

sorgelig, 2023-03-31:
wait... i didn't get it.. I flash redip-sid.bin into EEPROM from address 0. Do i have to burn bootloader.bin? From which address?

sorgelig, 2023-03-31:
```
make BOARD=redip-sid PRE_CLEAN=1 bootloader-clean

../build/project-rules.mk:56: c:/Work/oss-cad-suite/no2bootloader/gateware/ice40-stub/build-tmp/proj-deps.mk: No such file or directory
process_begin: CreateProcess(NULL, env bash C:\Work\oss-cad-suite\bin\yosys-config --datdir/ice40/cells_sim.v, ...) failed.
makefile:52: *** multiple target patterns.  Stop.
```

i've checked, there is really no no2bootloader/gateware/ice40-stub/build-tmp/proj-deps.mk
Even in repository there is no such file.
I've tried to make an empty one, but still no go..

```
make BOARD=redip-sid PRE_CLEAN=1 bootloader-clean
process_begin: CreateProcess(NULL, env bash C:\Work\oss-cad-suite\bin\yosys-config --datdir/ice40/cells_sim.v, ...) failed.
makefile:52: *** multiple target patterns.  Stop.
```

sorgelig, 2023-03-31:
by the way, may be it worth to connect ST pin from LM66200DRLR to I2C_SDA_BTN? it will automatically press the button and enter into dfu mode when USB is being connected.

sorgelig, 2023-04-01:
May be keep this issue opened to get more visibility for those who will also struggle with correct ROM flash?
Or update readme with short instruction and then it can be closed.

daglem, 2023-04-03:
I'll add instructions for flashing a blank board later, for the few people who assemble their own boards.

Regarding your point 3 above: You should be able to use muacm if you like, then you just use `dfu-util` without having to do the press button / powerup dance first. However since I still haven't been able to fit two SIDs + muacm on the FPGA, I have given instructions without muacm.

daglem, 2023-04-05:
Heh, you're right, something is off now. muacm used to work just fine. I'll investigate what could have changed, as I don't see off-hand what that might be.

muacm is a separate project. The source code for muacm can be found at https://github.com/no2fpga/no2muacm, however I have used a slightly modified pre-built version from https://github.com/no2fpga/no2muacm-bin

daglem, 2023-04-05:
> by the way, may be it worth to connect ST pin from LM66200DRLR to I2C_SDA_BTN? it will automatically press the button and enter into dfu mode when USB is being connected.

The USB interface is intended to be generic, e.g. it can conceivably be used for things like USB audio. Because of this I won't make changes to specifically tailor it to flashing.

muacm is intended for simplicity of flash upgrades (just connect and flash, regardless of whether the board was powered up first). I just have to get it working again.

daglem, 2023-04-05:
> MUACM doesn't work, actually.. So my original issue is exactly for this case. Once i've compiled and flashed bootloader it started to work with dfu-util. May be muacm precompiled netlist has compatibility issue. Do you have instruction how to produce muacm.v netlist from no2bootloader? Then i will make it from current bootloader sources.

muacm should work again now. Note that you still need the bootloader installed, muacm boots into that in order to flash.

sorgelig, 2023-04-05:
It doesn't fit into FPGA now. Strange, it was possible to compile before.
Anyway, it's not a big problem to press the button :)

daglem, 2023-04-05:
Currently, muacm will only fit if you choose the same model for both SIDs (i.e. both MOS6581 or both MOS8580).

I'm working on it :sweat_smile:

sorgelig, 2023-04-05:
Ah, that explains why.. I've used muacm before i started to play with 8580/6581 external switch. I think having muacm is not as important as having bug-less SID emulation.
It seems not all auto-detections of SID type work in reDIP-SID. I've tried Elvis wave playback cartridge - it detects reDIP-SID as 6581 always regardless type of emulated SID.

daglem, 2023-04-05:
Never heard of that cartridge - do you happen to have the SID model detection code it uses available?
Feel free to create separate issues for any incompatibilites.

ATM the emulation should be at least on par with reSID 0.16, with good 8580 emulation, and passable 6581 emulation. I'm working on freeing up resources which could be used for improved emulation and runtime configuration, if possible with muacm included at the same time.

sorgelig, 2023-04-05:
False alarm. Probably it was some hiccup while testing switch. I've just re-tested it - detected correct SID models.

sorgelig, 2023-04-05:
By the way, back to idea of using ST signal from LM66200. May be it can be used for quick detection of USB, so instead of muacm requiring many resources, you can check this signal and boot into bootloader. It can be made as an option.
Of course it will require a new PCB revision.. I don't know if USB connection can be detected by DP/DM signals without muacm.

sorgelig, 2023-04-05:
I just discovered that `btn` signal (from `sgtl5000_init`) can be connected to `boot` of `ice40_init`. So it's possible switch to bootloader any time which is convenient when you experiment with firmware, so you don't need to re-plug USB every time and keep connector more healthy. It's also easier than trying to hold pressed such tiny button while connecting USB.
So, may be you will consider this function as well.

sorgelig, 2023-04-05:
sorry for spamming, but i found the method not requiring pcb modifications:

1) add pullup for usb_d_p and usb_d_n
2) use ```boot <= boot | bootloader | ~btn | ~(usb_d_p & usb_d_n);```

That's all. Once you connect USB, it will immediately switch to bootloader. no muacm required.

sorgelig, 2023-04-06:
that's almost exactly what i did ;)

daglem, 2023-04-06:
Assuming that an unconnected EIR will be biased at VAG (currently configured to 1.5V), you could possibly just connect a three way switch between GND and 3.3V, with the middle pin connected to EIR. Both GND and 3.3V are available on the programming header. But perhaps adding external components is preferable to having to solder on the board? :man_shrugging:

In any case I think you would have to disable the ADC analog zero cross detector in by changing the value written to `CHIP_ANA_CTRL` in `sgtl5000_init_data.hex` (change `00 24 01 37` to `00 24 01 35`), and of course also split out the right channel input for detection instead of mixing in `redip_sid.sv`. Be warned that I've never tested whether my I2S implementation works for input :sweat_smile:

sorgelig, 2023-04-06:
I still prefer A5+A8 :) Stereo/dual SID is not interesting to me, so these pins aren't used anyway.

Closed 2023-04-05.

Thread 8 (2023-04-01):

Suggestion for mono dual-chip switch

sorgelig, 2023-04-01:
Hi!
I suggest to use A5 and A8 inputs as 8580/6581 modes switch when compiled as a single SID (SID2 not defined).

i propose to changes into lines: https://github.com/daglem/reDIP-SID/blob/c4514e9e33d27e8cd482e8126472a7c23486bb5e/gateware/sid_api.sv#L74-L75

change it to:
```systemverilog
    sid::cfg_t  sid1_cfg = {  cs.a5 ? sid::MOS8580 : sid::MOS6581, sid::D400, 9'd250, -11'sd384 };
    sid::cfg_t  sid2_cfg = { ~cs.a8 ? sid::MOS8580 : sid::MOS6581, sid::D400, 9'd250, -11'sd384 };
```
{A8,A5} will do:
11 - 8581+6580
01 - 2x6581
10 - 2x8580

So, if user will connect 3-positions switch to A8 and A5 with middle pin to GND, then in middle position it will be a mix of 6581 and 8580 and on side positions it will be either 6581 or 8580. Similar to SIDFX board.
in pcf file these pins need to be pulled up which shouldn't harm as pullup resistor is very weak (20K-100K). So it won't require external pullup resistors.

I believe 99% users will need this mode. Generic user just need to play games and thus simply need to switch between 6581 and 8580 in real time.

I've also added -384 fc_offset, so 6581 mode sounds more generic way like 6581R2/R3 (R4, R4AR are muffling IMHO).

If you want, i can make pull request with required changes.

daglem, 2023-04-03:
The plan is to add software configuration (ideally with two SIDs), however I'll consider your switch idea for single SID gateware later, when I have finished up all the other stuff I have planned. I won't be merging any PRs for now, since that would only detract from the work I'm doing.

Since you're playing with this now, I'll just mention that the default pullup value is 100K (it shouldn't be necessary to change the pcf file), however you have to actually configure the pullup for the IO pad - see how it's done for `pad_phi2` in `sid_io.sv`.

sorgelig, 2023-04-03:
I've already checked. There is no pullup by default. If i touch pin by GND and remove then it will keep logic 0 for some time. So there is no pullup if not explicitly configured in pcf. After adding pullup in PCF, it started to work correctly.

> The plan is to add software configuration (ideally with two SIDs), however I'll consider your switch idea for single SID gateware later

Static software configuration is not convenient in mono mode. I often like to switch between 8580 and 6581 while listening the music.

daglem, 2023-04-05:
> I've already checked. There is no pullup by default. If i touch pin by GND and remove then it will keep logic 0 for some time. So there is no pullup if not explicitly configured in pcf. After adding pullup in PCF, it started to work correctly.
>

Could it be that you didn't set the `PULLUP` as in the example I pointed to above? My point was just that the pullup value defaults to 100K _when turned on_, and that configuring on/off can be done (dynamically, if so desired) without changing the pcf file. I guess it doesn't matter much in this case.

> Static software configuration is not convenient in mono mode. I often like to switch between 8580 and 6581 while listening the music.

The plan is to add dynamic configuration via register writes, but in any case having an option for a physical switch is interesting, and I'll consider it later. In the mean time, just configure as fits you best.

sorgelig, 2023-04-05:
> Could it be that you didn't set the `PULLUP` as in the example I pointed to above? My point was just that the pullup value defaults to 100K _when turned on_, and that configuring on/off can be done (dynamically, if so desired) without changing the pcf file. I guess it doesn't matter much in this case.

I see now. I didn't understand your answer before. I will try your suggestion.

sorgelig, 2023-04-05:
Yes, `.PULLUP(1'b1)` for `io_cs` works fine too.

vanfanel, 2024-06-13:
@sorgelig Did you consider to bring this SID engine to the MiSTer C64 core?
If not, why? Is current C64 SID more accurate?

sorgelig, 2024-06-13:
Current SID implementation in MiSTer is very accurate. It also has many useful functions such as filter customization allowing to simulate different SID revisions. It's quite mature and tested in many games.

vanfanel, 2024-06-13:
> Current SID implementation in MiSTer is very accurate. It also has many useful functions such as filter customization allowing to simulate different SID revisions. It's quite mature and tested in many games.

That's my understanding, too. It sounds perfect to me.
So you also prefer the current SID implementation on MiSTer to current reDIP-SID... This confirms my impressions from hearing both.

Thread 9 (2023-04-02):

Pot discharge - is it safe?

sorgelig, 2023-04-02:
Hi!

I don't see any resistor in series for potX/Y, it means when pot is in lower resistivity state (~0 Ohm) with strong 5V drive and FPGA is pulling it down to GND then high current will flow. Isn't it dangerous for FPGA/level-shifter/4066?

daglem, 2023-04-04:
Good catch!

Checking IBIS files for the FPGA and the bus switch, the current would be in the order of 50mA using normal IO. Even with a 50% duty cycle this probably wouldn't be healthy for neither the 4066 or the FPGA in the long run.

This issue is fixed by using the RGB current drive, as originally planned. See the commit above.

Closed 2023-04-04.

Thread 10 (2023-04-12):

5V-tolerant FPGA?

sorgelig, 2023-04-12:
Hi!

in readme you wrote:
```
All FPGA I/O is 5V tolerant, and can drive 5V TTL.
```
If it is true then why board uses level shifter?

daglem, 2023-04-12:
The FPGA I/O is only available on the pin headers, and there it is 5V tolerant, because of the level shifter.

The FPGA in itself is not 5V tolerant.

sorgelig, 2023-04-12:
May be it's worth to modify readme to `All board I/O is 5V tolerant` instead `FPGA`

Closed 2023-04-12.

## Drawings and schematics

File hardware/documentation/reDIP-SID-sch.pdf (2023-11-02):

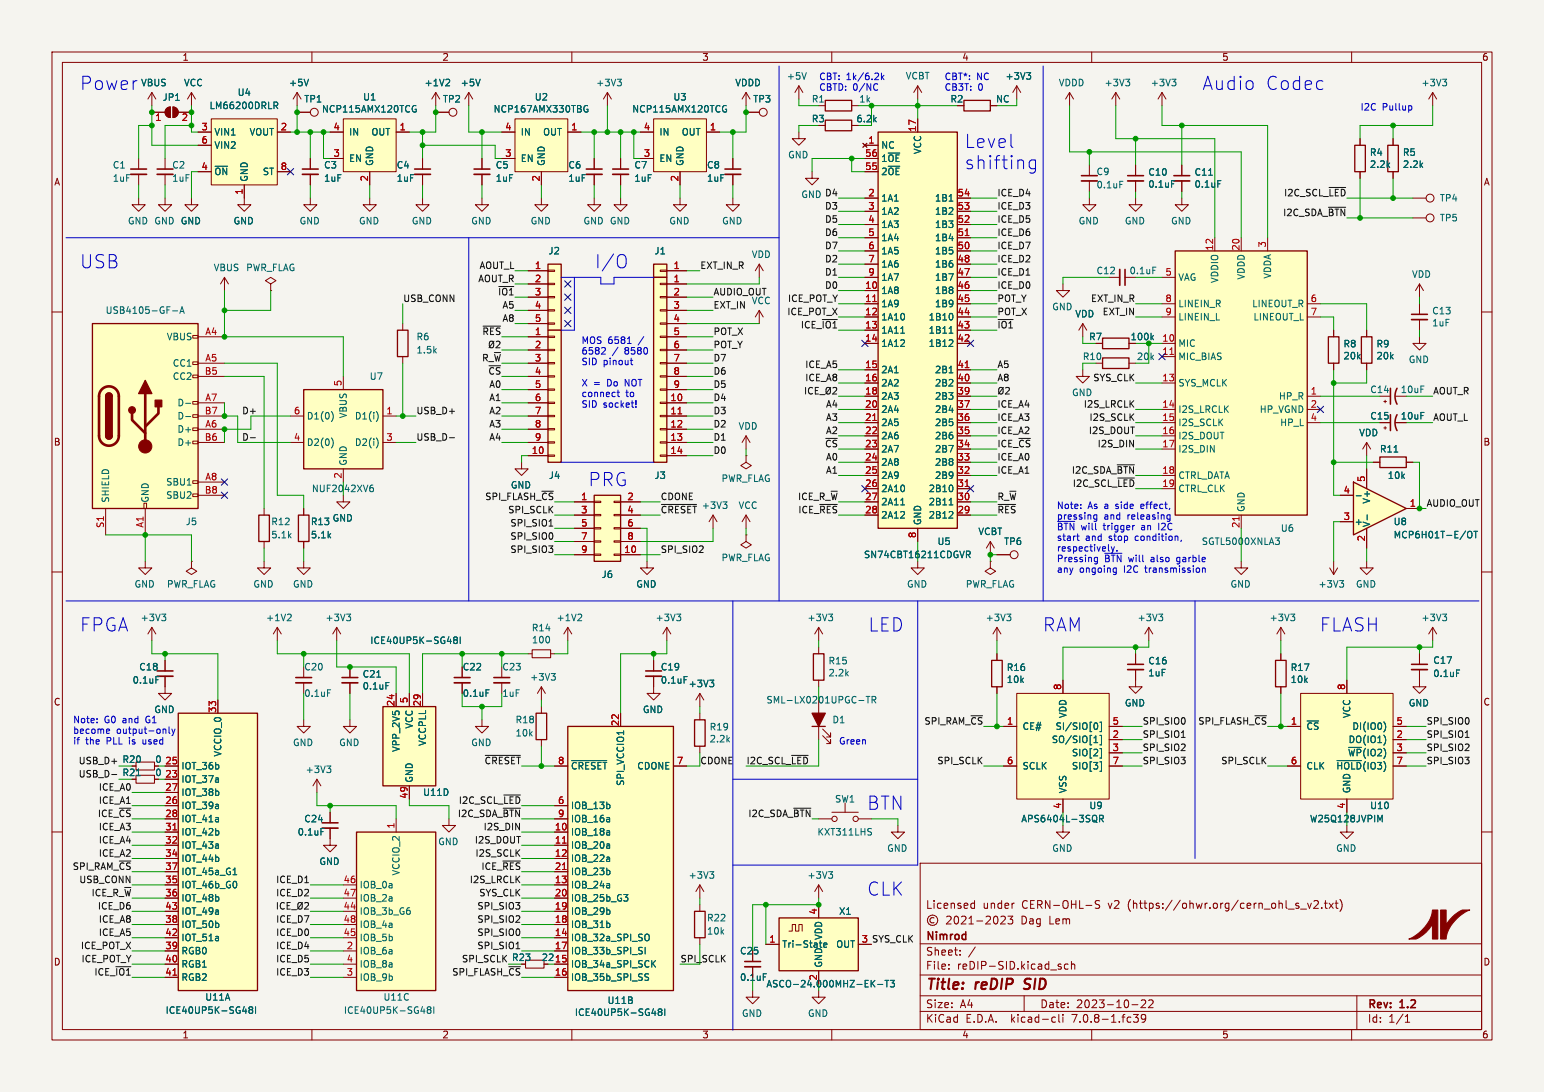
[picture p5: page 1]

I2C Pullup CBT: 1k/6.2k CBTD: 0/NC

any ongoing I2C transmission Audio Codec

connect to SID socket! PRG

Note: As a side effect, pressing and releasing

~{BTN}will trigger an I2C
start and stop condition, respectively.

Pressing ~{BTN}will also garble

4 SI/SIO[0] 5 SCLK 6 SIO[3] 7 VDD

4 DI(IO0) 5 CLK 6 ~{HOLD}(IO3) 7 VCC

File: reDIP-SID.kicad_sch Sheet: / Nimrod

4X1 ASCO-24.000MHZ-EK-T3 GND GND

Id: 1/1 Title: reDIP SID

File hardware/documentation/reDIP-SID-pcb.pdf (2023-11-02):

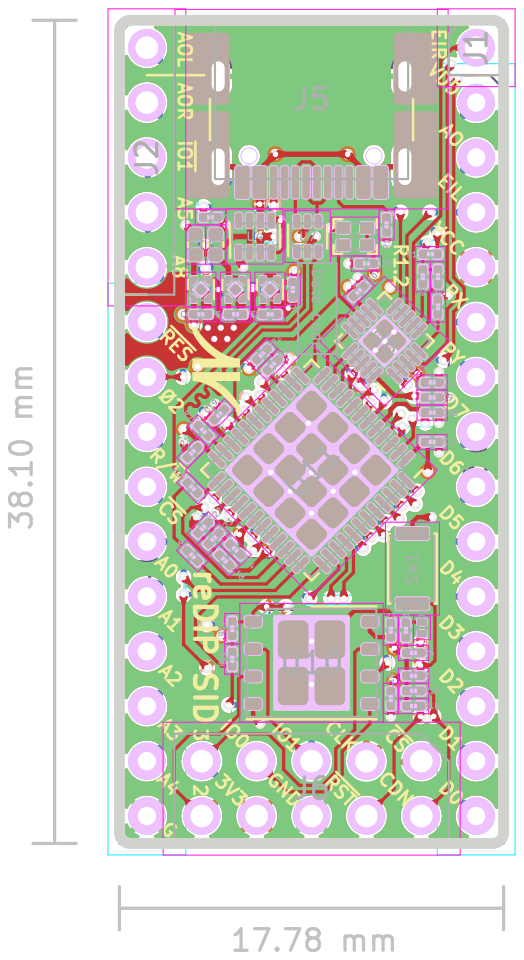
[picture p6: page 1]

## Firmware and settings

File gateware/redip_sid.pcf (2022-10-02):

# Pin Constraints File for reDIP SID - iCE40UP5K-SG48I

# Clock frequencies (nextpnr only)
set_frequency sys_clk 24.0
set_frequency i2s_sclk 6.144  # 64 * 96kHz
# set_frequency usb_clk 48.0

# System clock
set_io -nowarn sys_clk 20

# I2C + button / LED (shared)
set_io -nowarn i2c_scl_led_n 6
set_io -nowarn i2c_sda_btn_n 9

# I2S
set_io -nowarn i2s_din   10
set_io -nowarn i2s_dout  11
set_io -nowarn i2s_sclk  12
set_io -nowarn i2s_lrclk 13

# SPI
set_io -nowarn spi_sio0       14  # MOSI
set_io -nowarn spi_sio1       17  # MISO
set_io -nowarn spi_sio2       18
set_io -nowarn spi_sio3       19
set_io -nowarn spi_clk        15
set_io -nowarn spi_flash_cs_n 16
set_io -nowarn spi_ram_cs_n   37

# USB
set_io -nowarn usb_d_p  25
set_io -nowarn usb_d_n  23
set_io -nowarn usb_conn 35

# SID I/O

# SID address bus (A0-A4)
set_io -nowarn a0 27
set_io -nowarn a1 26
set_io -nowarn a2 34
set_io -nowarn a3 31
set_io -nowarn a4 32

# SID data bus (D0-D7)
set_io -nowarn d0 45
set_io -nowarn d1 46
set_io -nowarn d2 47
set_io -nowarn d3  3
set_io -nowarn d4  2
set_io -nowarn d5  4
set_io -nowarn d6 43
set_io -nowarn d7 48

# SID R/W
set_io -nowarn r_w_n 36

# SID CS
set_io -nowarn cs_n     28
# Extra chip select
set_io -nowarn cs_io1_n 41
# Extra address pins
set_io -nowarn a5       42
set_io -nowarn a8       38

# SID Ø2 (master clock)
set_io -nowarn phi2 44

# SID RES
set_io -nowarn res_n 21

# SID A/D converter inputs
set_io -nowarn pot_x 39
set_io -nowarn pot_y 40

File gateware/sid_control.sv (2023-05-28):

// ----------------------------------------------------------------------------
// This file is part of reDIP SID, a MOS 6581/8580 SID FPGA emulation platform.
// Copyright (C) 2023  Dag Lem <resid@nimrod.no>
//
// This source describes Open Hardware and is licensed under the CERN-OHL-S v2.
//
// You may redistribute and modify this source and make products using it under
// the terms of the CERN-OHL-S v2 (https://ohwr.org/cern_ohl_s_v2.txt).
//
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
// Source location: https://github.com/daglem/reDIP-SID
// ----------------------------------------------------------------------------

`default_nettype none

// SID control registers for two chips.
// Fully pipelined operation, shifting out registers for one voice per cycle.
module sid_control #(
    localparam DBUS_VALUE_TTL_MOS6581 = 10'd7,
    localparam DBUS_VALUE_TTL_MOS8580 = 10'd664
)(
    input  logic               clk,
    input  logic               tick_ms,
    input  sid::cycle_t        voice_cycle,
    input  sid::cycle_t        filter_cycle,
    input  sid::bus_i_t        bus_i,
    input  logic [1:0]         cs,
    input  logic [1:0]         model,
    // Write-only registers.
    output sid::freq_pw_t      freq_pw_1,
    output logic [2:0]         test,
    output logic [2:0]         sync,
    output sid::control_t      control_4,
    output sid::envelope_reg_t ereg_5,
    output sid::filter_reg_t   freg_1,
    // Read-only registers.
    input  sid::misc_reg_t     mreg,
    output sid::reg8_t         data_o
);

    /* verilator lint_off LITENDIAN */
    typedef union packed {
        logic [0:6][7:0] bytes;
        sid::voice_reg_t regs;
    } voice_ctrl_t;

    typedef union packed {
        logic [0:3][7:0] bytes;
        sid::filter_reg_t regs;
    } filter_ctrl_t;

    typedef union packed {
        logic [0:3][7:0] bytes;
        sid::misc_reg_t  regs;
    } misc_ctrl_t;
    /* verilator lint_on LITENDIAN */

    // Register sets for two SID chips.
    // Handling of nowrshmsk for structs was added to Yosys to save 10% of the
    // LCs in this design.
    (* nowrshmsk *)
    voice_ctrl_t  v5 = '0, v4 = '0, v3 = '0, v2 = '0, v1 = '0, v0 = '0;
    (* nowrshmsk *)
    filter_ctrl_t f1 = '0, f0 = '0;
    misc_ctrl_t   m;

    // Value on data bus.
    // FIXME: Yosys doesn't support multidimensional packed arrays outside
    // of structs, nor arrays of structs.
    typedef struct packed {
        logic [1:0][7:0] value;
        logic [1:0][9:0] age;
    } dbus_t;

    (* nowrshmsk *)
    dbus_t dbus = '0;

    // Register offset.
    logic signed [4:0] vaddr_offset = 0;

    always_ff @(posedge clk) begin
        if (voice_cycle == 3 || voice_cycle == 6) begin
            vaddr_offset <= 0;
        end else if (voice_cycle >= 1 && voice_cycle <= 2 ||
                     voice_cycle >= 4 && voice_cycle <= 5)
        begin
            // Subtract a constant here so we can add instead of subtract the
            // variable later, saving LCs which would otherwise be used for
            // two's complement inversion.
            vaddr_offset <= vaddr_offset - 7;
        end
    end

    // Register read / write.
    logic cycle_cs;
    logic signed [5:0] vaddr;
    logic signed [5:0] faddr;
    logic signed [5:0] maddr;
    logic r;
    logic w;
    sid::reg8_t r_value;

    always_comb begin
        // Assign to / from ports.
        freq_pw_1 = v0.regs.waveform.freq_pw;
        control_4 = v3.regs.waveform.control;
        ereg_5    = v4.regs.envelope;
        test      = { v2.regs.waveform.control.test, v1.regs.waveform.control.test, v0.regs.waveform.control.test };
        sync      = { v2.regs.waveform.control.sync, v1.regs.waveform.control.sync, v0.regs.waveform.control.sync };
        freg_1    = f1.regs;  // Rotated before first use
        m.regs    = mreg;

        // cycle bit 2 is set for voice 4 - 6.
        cycle_cs = cs[voice_cycle[2]];
        // cycle_cs = cs[voice_cycle >= 4];

        // Address offsets.
        vaddr = signed'(6'(bus_i.addr)) + 6'(vaddr_offset);
        faddr = signed'(6'(bus_i.addr)) - 'sh15;
        maddr = signed'(6'(bus_i.addr)) - 'sh19;

        // Read / write.
        r =  bus_i.phi2 &  bus_i.r_w_n && maddr >= 0 && maddr <= 3;
        w = ~bus_i.phi2 & ~bus_i.r_w_n && voice_cycle >= 1 && voice_cycle <= 6;

        // FIXME: Verilator complains about m.bytes[maddr[1:0]].
        r_value  = m.bytes[maddr[2:0]];

        // Data output, default to SID 1 (for both SIDs at D400).
        // Read data could have been always output from dbus.value, however
        // this would delay the output by one cycle, possibly violating the
        // minimum MOS6510 TDSU of 100ns for SID 2 OSC3/ENV3.
        // data_o = dbus.value[cs == 2'b10];
        data_o = |cs && r ? r_value : dbus.value[cs == 2'b10];
    end

    // Value on data bus for each SID chip.
    // FIXME: Attempting to put the for loop inside always_ff makes Verilator fail with
    // %Error: Internal Error: sid_control.sv:147:55: ../V3LinkDot.cpp:2298: Bad package link
    // always_ff @(posedge clk) begin
    //     for (int i = 0; i < 2; i++) begin : sid
    for (genvar i = 0; i < 2; i++) begin : sid
        always_ff @(posedge clk) begin
            if (bus_i.res) begin
                dbus.value[i] <= '0;
                dbus.age[i]   <= '0;
            end else if (cs[i] && (r || w)) begin
                // Keep last register read/write on data bus.
                dbus.value[i] <= r ? r_value : bus_i.data;
                dbus.age[i]   <= 0;
            end else if (dbus.age[i] == ((model[i] == sid::MOS6581) ?
                                         DBUS_VALUE_TTL_MOS6581 :
                                         DBUS_VALUE_TTL_MOS8580))
            begin
                // Bus value has faded out.
                dbus.value[i] <= 0;
            end else if (voice_cycle == 1) begin
                // Count up to complete fade-out of bus value.
                dbus.age[i]   <= dbus.age[i] + 10'(tick_ms);
            end
        end
    end

    // Write-only registers.
    always_ff @(posedge clk) begin
        // Rotation on cycles 1 - 6 for writing.
        // Two additional complete freewheeling rotations to keep in sync with
        // sid_waveform.sv and sid_envelope.sv
        if (voice_cycle >= 1 && voice_cycle <= 18) begin
            { v5, v4, v3, v2, v1, v0 } <= { v4, v3, v2, v1, v0, v5 };

            if (bus_i.res) begin
                v0.bytes <= '0;
            end else if (cycle_cs && w && vaddr >= 0 && vaddr <= 6) begin
                // Voice register write.
                v0.bytes[vaddr[2:0]] <= bus_i.data;
            end
        end

        if (voice_cycle == 1 || voice_cycle == 4 ||
            filter_cycle == 5 || filter_cycle == 10)
        begin
            { f1, f0 } <= { f0, f1 };
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

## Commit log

2021-01-11 Moved Vcc via away from pin-in-paste stencil aperture
    [reDIP-SID.kicad_pcb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]
2021-01-13 Usability and manufacturability improvements
    * Made all iCE40 RGB pins externally available
    * Removed split in stencil apertures for pin-in-paste
    [reDIP-SID-B_Cu.gbr, reDIP-SID-B_Fab.gbr, reDIP-SID-B_Mask.gbr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]
2021-01-13 Re-added JP1 on back silk screen
    [reDIP-SID.kicad_pcb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]
2021-01-17 Usability and manufacturability improvements
    * Added extra vias for Vcc and 3.3V rails, for high power external devices
    * Added extra thermal via for SGTL5000
    * Assume 3x solder paste volume for paste-in-hole
    * Adjustments to fab and silk screen layers
    [reDIP-SID-B_Cu.gbr, reDIP-SID-B_Fab.gbr, reDIP-SID-B_Mask.gbr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]
2021-01-31 Adjusted TVSOP-56 footprint to match datasheet
    [reDIP-SID-B_Cu.gbr, reDIP-SID-B_Fab.gbr, reDIP-SID-B_Mask.gbr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]
2021-03-04 Various fixes
    * Added 10k pullup for SPI SCLK, following iCE40 Hardware Checklist
    * Reworked USB routing to not rely on any particular ESD IC (note swapped pins)
    * Widened a few tracks
    * Added silk screen on back side for SPI header
    * Increased courtyard for TVSOP-56 footprint
    * Changed VCC to power symbol
    * Corrected BOM for LDOs
    [reDIP-SID-BOM.xlsx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]
2021-03-04 Remember to add ray tracing for board image
    Is it possible to script output from the 3D viewer?
2021-04-18 Replaced non-stocked parts
    * Replaced 1.2V LDO with more readily available part
    * Changed oscillator reeling order number
    [reDIP-SID-BOM.xlsx, reDIP-SID.kicad_pcb, reDIP-SID.sch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]
2021-04-21 Attempt at reducing layer count from 6 to 4
    [reDIP-SID-B_Cu.gbr, reDIP-SID-B_Fab.gbr, reDIP-SID-B_Mask.gbr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]
2021-04-21 Removed splits in ground on layer In2.Cu, removed ground pour on layer B.Cu
    Changes suggested by zyp.
    [reDIP-SID-B_Cu.gbr, reDIP-SID-B_Fab.gbr, reDIP-SID-B_Mask.gbr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]
2021-04-22 Small cleanups
    * Removed ground split under USB D-
    * More ground fill on layer In2.Cu, in the vicinity of SPI traces
    * Slight improvents to SPI routing
    [reDIP-SID-B_Cu.gbr, reDIP-SID-B_Fab.gbr, reDIP-SID-B_Mask.gbr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]
2021-04-24 Showstopper fixes
    * Pins swaps and rerouting to handle the fact that iCE40UP5K pins 35 and 37
    are output only when the PLL is used
    * Removed Q1, USB_CONN is now used to pull up USB D+ directly through R3
    * Changed the oscillator to 24 MHz (full speed USB is clocked at 12 MHz)
    * Slight rounding of footprint pads for oscillator and button
    Many thanks go to @smunaut for pointing out the (undocumented!) iCE40 PLL
    peculiarities, and to zyp for pointing out that the PLL can't convert a
    24.576MHz clock to anything that will work for full speed USB.
    [reDIP-SID-BOM.xlsx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]
2021-04-25 Preparing for prototyping
    * Routing cleanups
    * Changed oscillator to ± 25 ppm part
    * Note on the PLL output-only-pin trap in the schematic
    Thanks to @DX-MON for pointing out that audio hardware should have
    as high frequency stability as possible.
    [reDIP-SID-BOM.xlsx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]
2021-04-27 Improved decoupling
    * Improved decoupling and PLL power filtering, as suggested by @smunaut
    * Minor cleanups on F.Fab layer
    * Added note in the schematic on the side effects of pressing the user button
    [reDIP-SID-B_Cu.gbr, reDIP-SID-B_Fab.gbr, reDIP-SID-B_Mask.gbr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]
2021-04-27 BOM update
    [reDIP-SID-BOM.xlsx]
2021-04-27 Files for manufacture
    * Added note on pin-in-paste for USB-C connector
    * Capped component position resolution to 0.01mm
    * Moved kicost BOM spreadsheet to documentation/
    * Files for fabrication and assembly generated by KiKit
    [bom.csv, reDIP-SID-BOM.xlsx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]
2021-04-28 Corrected files for manufacture
    "kikit fab pcbway" currently does not align layers and drills
    for designs with a specified auxiliary axis origin.
    For now, I have corrected this by making local changes to KiKit.
    Files for inner layers are also named to be consistent with
    outer layers, and are included in the .gbrjob file.
    Thanks to @DX-MON for the invaluable tip on re-checking the
    Gerber files after switching to using KiKit for file export.
    [reDIP-SID-NPTH.drl, reDIP-SID-PTH.drl, reDIP-SID.drl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]
2021-04-29 Removed J6 from BOM and centroid files
    [bom.csv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]
2021-09-03 Revision 1.0
    This revision rounds off the features of the board, both as a drop-in
    SID replacement, and as a generic FPGA platform for audio and / or 5V
    tolerant I/O:
    * Fully 6581 / 8580 pin compatible
    * Machined (round) socket pin headers, for mounting directly in a SID socket
    * C64 model detection by measurement of VDD on SGTL5000 MIC input
    * DC bias for SID audio output, required by C64 audio output stage
    * Hardware mixing of left and right audio channels into SID audio output
    * Stereo outputs, in addition to mono SID audio output
    * Stereo inputs
    * Schottky diodes replaced with power switch, minimizing 5V rail voltage drop
    * Separate LDO for SGTL5000 VDDD, avoiding overvoltage on iCE40 V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
    [bom.csv, reDIP-SID-BOM.xlsx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]
2021-09-03 Update of generated BOM
    [reDIP-SID-BOM.xlsx]
2021-09-03 Update of schematic pdf
2021-09-09 Tweaks before manufacture
    * Added test point for 5V rail
    * Got rid of one BOM line by changing the MIC voltage divider
    [reDIP-SID-BOM.xlsx, reDIP-SID.kicad_pcb, reDIP-SID.sch]
2021-09-13 Updated board images
2021-09-13 Made all test points equal
    [reDIP-SID.kicad_pcb, reDIP-SID.sch]
2021-09-14 Modified ESD protection footprint to accomodate other SOT-563 / SOT-666 devices
    [reDIP-SID.kicad_pcb, reDIP-SID.sch]
2021-09-16 Marked position for UL and date code
    [reDIP-SID.kicad_pcb]
2021-09-22 Update of PCB pdf
    [reDIP-SID.kicad_pcb]
2022-01-19 Migrated to KiCad 6
    [reDIP-SID.kicad_pcb, reDIP-SID.kicad_sch]
2022-03-26 Revision 1.1
    * Changed PSRAM back from LY68L6400SLIT to APS6404L-3SQR
    * Changed USB-C receptacle from HRO TYPE-C-M-12-31 to GCT USB4105-GF-A
    * Replaced FPF1321 with LM66200, removing a total of four components
    * Changed CDONE LED to turn on initially, and turn off after configuration
    * Reduced soldermask opening diameter for all encroached BTC thermal vias
    * Moved fabrication date code to board front
    * Silk screen updates
    * Updated all local footprints to new format
    * Update of pin header model from @smunaut
    [reDIP-SID-BOM.xlsx, reDIP-SID.kicad_pcb, reDIP-SID.kicad_sch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]
2022-03-26 Mark board only footprints as such
    [reDIP-SID.kicad_pcb, reDIP-SID.kicad_sch]
2022-04-08 Revision 1.1 enhancements
    * Added input capacitors for LM66200
    * Changed bus switch to SN74CBT16211A, voltage divider bias for level shifting
    * Routing and power plane cleanups
    [reDIP-SID-BOM.xlsx, reDIP-SID.kicad_pcb, reDIP-SID.kicad_sch]
2022-04-15 Board support for CBT, CBTD, and CB3T bus switches
    [reDIP-SID-BOM.xlsx, reDIP-SID.kicad_pcb, reDIP-SID.kicad_sch]
2022-04-18 Capacitor upgrade
    * GRM035R60J475ME15D -> GRM035R61A225ME01D
    * GRM033R60J224KE15D -> GRM033R60J224ME90D
    [reDIP-SID-BOM.xlsx, reDIP-SID.kicad_sch]
2022-05-30 Start of gateware
    This is a first attempt at an implementation of the 6581 DACs in SystemVerilog.
    Unfortunately this currently doesn't work with Yosys, since it cannot handle
    variables of data type real in initial constructs.
2022-10-02 MOS6581 / MOS8580 FPGA design
    This is a work in progress. The gateware is designed by someone who
    has never attempted a more advanced FPGA design than a "blinky", and
    nothing is tested, or even simulated. It goes without saying that the
    probability that anything will currently work is approximately 0.
    The design aims to be 100% cycle accurate, based on information from
    https://github.com/libsidplayfp/SID_schematics/wiki and
    https://github.com/daglem/reSID. The SID chip is a latched design,
    internally requiring a two phase non-overlapping clock. In order to
    emulate this in gateware using D flip-flops, four dummy clock phases
    are used - PHI2, PHI2_PHI1, PHI1, and PHI1_PHI2.
    The design includ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
    [redip_sid.pcf]
2022-10-02 Added titles to filter cutoff curve plot
2022-10-02 Remove KiCad as language again
2022-10-03 More intuitive filter curve offset
    * fc_offset = 0: Average 6581 filter curve
    * fc_offset < 0: Move curve to the left
    * fc_offset > 0: Move curve to the right
2022-10-08 There is sound in simulation
    No working filter yet, though.
2022-10-10 The filter is now working
2022-10-18 Keep filter states internal to sid_filter module
    This necessitates the introduction of sv2v, since Yosys doesn't
    currently support arrays of structs, and I couldn't find any good
    workaround in this case.
2022-10-20 Avoid muxing of filter states
    This also removes the requirement of sv2v.
2022-10-24 Registered IO for I2S, unmute ADC
2022-11-19 Audo simulation improvements
    * Enable the C64 external filter by default
    * Properly initialize the C64 external filter
    * Exit if the standard input is a terminal
2022-11-21 Reduced voice DC offset
    This brings the amplitude of volume samples relative to regular
    waveforms into the right ballpark.
2022-11-24 Configurable frequency band for simulated external filter
2022-11-26 Elaborate a bit on the simulated external filter
2023-03-24 Use a common microsecond timer for smaller counters in submodules
2023-04-04 Use RGB 2mA current drive for POT discharge
    This was planned when the board was designed, however when implementing
    the gateware the iCE40 techlib doc seemed to indicate that one couldn't
    read from a pin which uses the SB_RGBA_DRV primitive to drive current.
    So SB_IO was used for POT discharge and the RGB current drive was
    forgotten about, without considering that shorting a POT pin by applying
    ~5V while outputting 0 causes ~50mA to be drawn into the FPGA using
    normal IO.
    Luckily it turns out that SB_RGBA_DRV can be combined with SB_IO. When
    the current drive is turned off using RGBLEDEN or RGB0PWM / RGB1PWM, the
    pin input can be read using SB_IO.
    This fixes issue #9, thanks to @sorgelig f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
2023-04-04 Updated OSS CAD Suite
2023-04-06 Simplified procedure for flashing when μACM is not configured
    If μACM is not configured, drop into the bootloader on detection
    of a physical USB connection.
    Thanks to @sorgelig for the idea.
2023-05-06 Pipelining
    This is a major rewrite, pipelining all modules in the SID chip in order to
    save FPGA resources:
    * Power-on initialization of oscillators, noise LFSRs, and envelope counters
    * Register writes
    * Update and synchronization of oscillators
    * Waveform generation
    * Envelope generation
    * Voice DCA
    * Filter / audio output
2023-05-15 Waveform writeback
    * Zeroing of the 6581 oscillator MSB via combined waveforms
    * Zeroing of noise LFSR bits via combined waveforms
    Avoid additional storage for oscillator and noise LFSR states by
    freewheeling rotation.
    [sid_control.sv]
2023-05-19 Program to correctly sample 6581 pulse + sawtooth
2023-05-20 Samples for complete 6581 pulse + sawtooth waveform
2023-05-23 Corrected 8580 waveform 0, improved framework for noise LFSR writeback
    [sid_control.sv]
2023-06-18 Sample all 6581 combined waveforms
    All combined waveforms which include sawtooth are affected by
    writeback to oscillator bit 23.
    Sample all combined waveforms except those which include noise.
2023-11-02 Revision 1.2
    * Updated to KiCad 7
    * Removed CDONE LED
    * Added CRESET pull-up resistor
    * Added via teardrops
    * Increased hole size for circular pin headers
    * Replaced "last time buy" SN74CBT16211ADGVR
    with SN74CBT16211CDGVR
    * Added example part numbers for pin headers
    [reDIP-SID-BOM.xlsx, reDIP-SID.kicad_pcb, reDIP-SID.kicad_sch]
2024-09-23 Correct MOS6581 combined waveforms
    The MOS6581 OSC3 combined waveform samples in reSID were obtained around 25 years ago.
    At the time, it was not known that the MOS6581 oscillator MSB can be zeroed via combined waveforms which include sawtooth.
    Complete MOS6581 and MOS8580 OSC3 combined waveform samples are now included. MOS6581 samples are supplied by Tuomas "Trurl" Rantala.
    OSC3 waveform samples can be generated by running the program combsample.prg on a C64.
    Boolean expressions for sawtooth+triangle and pulse+sawtooth+triangle can now be generated by the program waveform-sop.pl
    Note that OSC3 combined waveform samples vary greatly between different SID chips.
